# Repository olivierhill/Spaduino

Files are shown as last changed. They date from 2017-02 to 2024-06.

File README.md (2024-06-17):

# Spaduino
Arduino sketch that let you talk to your Calspa controller over I2C

Tested on an ATmega328P running at 3.3V/8MHz. Works on a 2012 Cal Spa with a Balboa controller CS6200DV. Other Balboa based controller with "dumb" Top Side displays might work.

Flash your chip with this sketch. You need to connect wires similar to this:

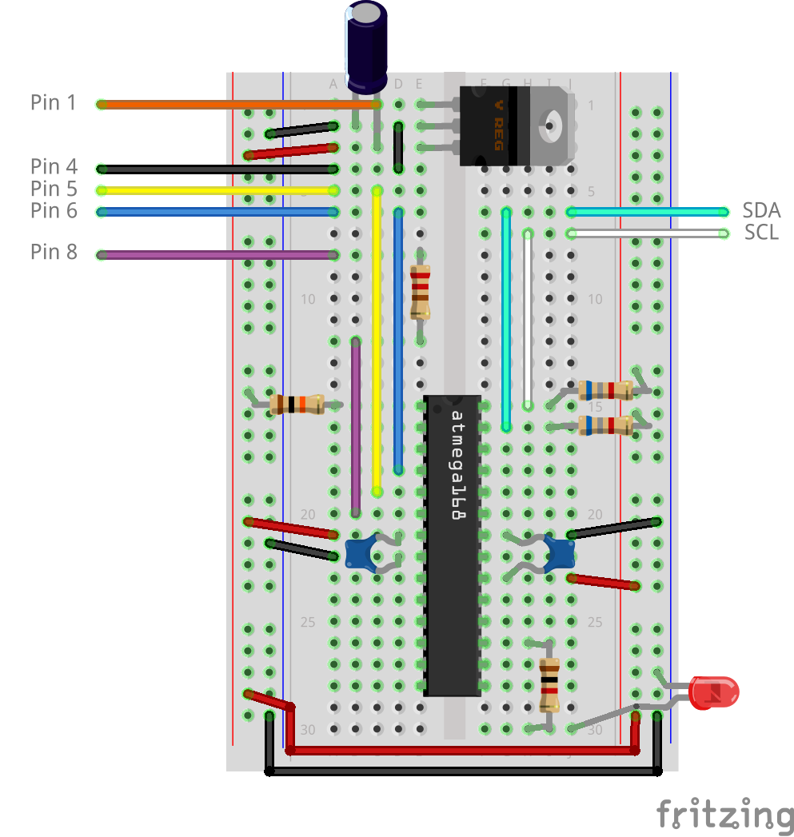
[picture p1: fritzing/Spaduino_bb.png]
Breadboard for Spaduino


I use this setup with a WiFi microcontroller to monitor the hot tub remotely using MQTT.

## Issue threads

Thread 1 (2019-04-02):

Some questions

jantenhove, 2019-04-02:
First of all, thanks for doing the hard work on decoding the protocol.
I want to try to use your project as a starting base for controlling my spa. It has a display with more buttons and a different Balboa controller, but it also has 2 RJ45 connector, so I hope i can reuse (a part) of your code on the second connector.
I have a few questions:
- The balboa spa operates on 5V, the ATmega328P on 3.3V, yet the signals from the spa are directly connected to the Atmega inputs. Are those 3.3V?
- You did not connect the pins 2, 3 and 7. Just because you don't use them? I plan to connect them using the same resistor as the temperature button.

olivierhill, 2019-04-02:
Depending on many buttons the top display has, it might or might not be a different protocol. Some use an SPI protocol instead of the proprietary 7-bit that was coded here.

As for your two questions, the Balboba does operate at 5V. The ATmega is not really 5V tolerant on 3.3V but the clock and data signal are mostly at 0V. If you were to feed a constant 5V it would fry the ATmega. If you really want to be safe you can pass these through a voltage divider or a CMOS voltage converter. A bunch of 78xx chips can be used for those. I've been running mine since 2016 constantly and it still works.

The other pins are for Pump 1&2 and Lights. You can see the pinout here: https://www.olivierhill.ca/archives/74-Cal-Spa-Connector.html

olivierhill, 2019-04-02:
Depending on many buttons the top display has, it might or might not be a different protocol. Some use an SPI protocol instead of the proprietary 7-bit that was coded here.

As for your two questions, the Balboba does operate at 5V. The ATmega is not really 5V tolerant on 3.3V but the clock and data signal are mostly at 0V. If you were to feed a constant 5V it would fry the ATmega. If you really want to be safe you can pass these through a voltage divider or a CMOS voltage converter. A bunch of 78xx chips can be used for those. I've been running mine since 2016 constantly and it still works.

The other pins are for Pump 1&2 and Lights. You can see the pinout here: https://www.olivierhill.ca/archives/74-Cal-Spa-Connector.html

Closed 2019-04-03.

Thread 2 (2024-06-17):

CalSpas 407T and CS6215R1A

smitterer, 2024-06-17:
Hi!

I see this repository wasn't updated for a pretty long time but also the controller is pretty old, so might not be a problem.

Do you know if this would work with CalSpas 407T and CS6215R1A?

BTW, the link to http://www.olivierhill.ca/archives/74-Cal-Spa-Connector.html doesn't work.

Thanks!

olivierhill, 2024-06-17:
I do not own the spa anymore, the controller looks similar to what I had with an 8 pin plug, but I cannot make any guarantee, this is just code I used in the past, YMMV

smitterer, 2024-06-17:
Thanks for your feedback.
Did yours just have the 8 pin plug (Molex) and still use the RJ45 or did you go via the 8 pin plug?

How did you then connect to the atmega? Via an esp?

Thanks!

Closed 2024-06-17.

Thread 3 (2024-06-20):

RJ45 or 8 Pin Molex

smitterer, 2024-06-20:
Hi!

Did you use the RJ45 or a Molex-Connector?

Would you be able to republish https://www.olivierhill.ca/archives/74-Cal-Spa-Connector.html / make it public again?

Thanks!

olivierhill, 2024-06-20:
Please understand this is a bug tracker and not a support forum. You can send PRs and the code is provided as-is according to the attached license.

You can thank AI for the destruction of web pages, I do not have archives.

Closed 2024-06-20.

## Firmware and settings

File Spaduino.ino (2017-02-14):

/*
 * Copyright 2017 Olivier Hill
 * 
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
 * You should have received a copy of the GNU General Public License
 * along with this program.  If not, see <http://www.gnu.org/licenses/>.
**/

#include <Wire.h>
#include <avr/sleep.h>
#include <avr/power.h>

//#define DEBUG 1

const uint8_t PUSH_DELAY = 100; // Seems to want ~100ms for debouncing
const byte    MY_ADDRESS = 82;  // I2C Address

uint32_t buf;
volatile __uint24 display;
volatile boolean changed;

struct 
{
  char    c_str[4];
  uint8_t int_v;
  uint8_t target;
} temperature;

// list of commands
enum {
  CMD_ID      = 1, // ID of device (always answers 0xBA)
  CMD_DISPLAY = 2, // Current display, temperature or message
  CMD_SETTEMP = 3, // Set target temperature
  CMD_GETTEMP = 4, // Get current target temperature
  CMD_STATUS  = 5  // Get current status (heater running, etc.)
};

volatile struct 
{
  byte command;
  byte argument;
  bool in_progress;
} request;
    
void setup()
{
  // disable ADC
  ADCSRA = 0;
  ACSR = bit(ACD); //Disable the analog comparator

  // Running on internal 8MHz clock, but could use this for an Arduino
  //CLKPR = _BV(CLKPCE);
  //CLKPR = 0x01; // 8MHz

  power_adc_disable();    // ADC
  power_spi_disable();    // SPI
  power_usart0_disable(); // Serial
  power_timer1_disable(); // Timer 1

  // I2C Slave
  Wire.begin (MY_ADDRESS);
  Wire.onReceive(receiveEvent);
  Wire.onRequest(requestEvent);

  // Disable internal pullups
  digitalWrite(SDA, 0);
  digitalWrite(SCL, 0);

  pinMode(2,  INPUT);  // CLK
  pinMode(3,  INPUT);  // Data
  pinMode(4,  INPUT);  // Temperature
  pinMode(11, OUTPUT); // Counter toggle
  pinMode(13, INPUT);  // Disable status LED

  // interrupt for SS rising edge (pin 2)
  EICRA &= ~(bit(ISC00) | bit (ISC01));  // clear existing flags
  EICRA |=  bit (ISC01) | bit (ISC00);   // rising edge interrupt
  EIFR   =  bit (INTF0);    // clear flag for interrupt 0
  EIMSK |=  bit (INT0);     // enable it
 
  // reset Timer 2
  TCCR2A = 0;
  TCCR2B = 0;
  
  // Timer 2
  // 8 MHz clock, prescale of 32
  // 125 ns per tick * 32 = 4 µs
  // Count 125 gives 500 µs (0,5 ms)
  TCCR2A = bit (WGM21) | bit (COM2A0);   // CTC mode, toggle on pin 10
  OCR2A  = 124;

  // Timer 2 interrupt
  TIMSK2 = bit (OCIE2A);

  // Reset count to 0
  TCNT2 = 0;

#ifdef DEBUG
  Serial.begin(74880);
  Serial.println(F("Started"));
#endif
}

// CLK rising ISR
ISR (INT0_vect)
{
  // Grab pin before it changes
  byte c = PIND;

  // Test if we are in "writing mode", was Timer 2 started yet?
  if (TCCR2B) {
    TCNT2 = 0; // Reset our counter to zero
  }
  else {
    buf = 0xAA;  // Initial value (padding)

    OCR2A = 124; // Count to 125
    TCNT2 = 0;   // Reset counter to zero

    // Start Timer 2
    TCCR2B = bit (CS21) | bit (CS20); // prescaler of 32
  }

  // Shift buffer and add our pin value
  buf <<= 1;
  buf |= (c >> 3) & 0x01;
} // end of INT0_vect

ISR (TIMER2_COMPA_vect) 
{
  TCCR2B = 0; // stop timer 2 (we keep TCCR2A set for CTC next cycle)
  TCNT2  = 0; // For next timer loop, reset to zero

  // Test if we have a complete 3x7 bit sequence
  if (buf >> 21 == 0xAA)
  { 
    buf &= 0x001fffff; // Only keep 21 bits

    if (display != buf) {
      display = buf;
      changed = true;
    }
  }
}

// called by interrupt service routine when incoming data arrives
void receiveEvent (int howMany)
{
  request.command = Wire.read();

  if (howMany > 1) {
    request.argument = Wire.read();
  }

  request.in_progress = false;

  // Empty buffer to /dev/null
  while (Wire.available () > 0) 
    Wire.read ();

} // end of receiveEvent

void requestEvent()
{
  switch (request.command)
  {
    case CMD_ID:
      Wire.write(0xBA);
      break;
    case CMD_DISPLAY:
      // Temperature is updated in main loop, simply output
      // the buffer here, we are in an ISR
      Wire.write(temperature.c_str, sizeof temperature.c_str );
      break;
    case CMD_GETTEMP:
      Wire.write(temperature.target);
      break;
    case CMD_STATUS:
      byte status = (display >> 14) & 0x0f;
      Wire.write(status);
      break;
  }
}

char getChar(byte c)
{
  // This will generate a lookup table from 7-segment
  // display to ASCII chars. Some chars are represented
  // by a number instead of letter (ie: O is 0).
  switch (c) {
    case 0x7e:
      return '0';
    case 0x30:
      return '1';
    case 0x6d:
      return '2';
    case 0x79:
      return '3';
    case 0x33:
      return '4';
    case 0x5b:
      return '5';
    case 0x5f:
      return '6';
    case 0x70:
      return '7';
    case 0x7f:
      return '8';
    case 0x73:
      return '9';
    case 0x77:
      return 'A';
    case 0x1f:
      return 'b';
    case 0x0d:
      return 'c';
    case 0x4e:
      return 'C';
    case 0x3d:
      return 'd';
    case 0x4f:
      return 'E';
    case 0x47:
      return 'F';
    case 0x37:
      return 'H';
    case 0x0e:
      return 'L';
    case 0x15:
      return 'n';
    case 0x67:
      return 'P';
    case 0x05:
      return 'r';
    case 0x0f:
      return 't';
    case 0x3e:
      return 'U';
    case 0x3b:
      return 'Y';
    case 0x01:
      return '-';
    case 0x00:
      return ' ';
    default:
      return '?';
  }
}

char getLetter(byte c)
{
  switch(c) {
    case '5':
      return 'S';
      break;
    case '1':
      return 'I';
      break;
    case '0':
      return 'O';
      break;
    default:
      return c;
  }
}

void getDisplay()
{
  __uint24 dispCopy = display; // Grab before it changes

  dispCopy &= 0x1c3fff; // Discard what's not on display (3rd byte LSB)

  for (int8_t i=2; i>=0; i--) {
    if (i < 2 && temperature.c_str[2] >> 6 != 0) // Not a digit
      temperature.c_str[i] = getLetter(getChar(dispCopy >> ((2-i)*7) & 0x7f));
    else
      temperature.c_str[i] = getChar(dispCopy >> ((2-i)*7) & 0x7f);
  }
  temperature.c_str[3] = 0x00;

  // Is it a valid numerical temperature? If not, translate to letters
  temperature.int_v = atoi(temperature.c_str);
}

void togglePin(uint8_t pin)
{
#ifdef DEBUG
  Serial.print(millis());
  Serial.print(F(": Toggling pin "));
  Serial.println(pin, HEX);
#endif

  pinMode(pin, OUTPUT);
  digitalWrite(pin, HIGH);
  delay(PUSH_DELAY);
  digitalWrite(pin, LOW);
  pinMode(pin, INPUT); // Hi-Z
}

bool waitForBlink()
{
  // Wait for display to blink
  for (uint8_t j=0; j < 30; j++) { // Wait for 3 sec max. (30 x 100ms)
    if (!changed || display & 0x3fff != 0) {
      delay(100);
    }
    else {
      changed = false; // Reset our change flag to see next temp
      return true;
    }
  }
  return false;
}

// main loop
void loop (void)
{
  // Make sure we run it once between receiveEvent and requestEvent
  if (request.in_progress == false)
  {
    request.in_progress = true;

    switch (request.command) {
      case CMD_DISPLAY:
#ifdef DEBUG
        Serial.print(millis());
        Serial.println(F(": Reading display"));
#endif
        getDisplay();
        break;
      case CMD_SETTEMP:
#ifdef DEBUG
        Serial.println();
        Serial.println(String(millis()) + F(": Trying to set temperature to: ") + String(request.argument, DEC));
#endif

        changed = false;
        togglePin(4);

        waitForBlink();
        
        for (uint8_t i=0; i < 40; i++) { // Up to 40 button push
          // wait for change and a valid temp
          for (uint8_t j=0; j < 20; j++) { // Wait for 2 sec max. (20 x 100ms)
            if (!changed || temperature.int_v < 80) {
              delay(100);
              getDisplay();
            }
            else
              break;
          }

          if (temperature.int_v < 80) {
#ifdef DEBUG
            Serial.println(String(millis()) + F(": Something went wrong"));
#endif
            break;
          }

#ifdef DEBUG
          Serial.print(millis());
          Serial.print(F(": Current target is: "));
          Serial.println(temperature.int_v, DEC);
#endif

          if (temperature.int_v == request.argument) {
#ifdef DEBUG
            Serial.print(millis());
            Serial.println(F(": All done"));
#endif
            temperature.target = temperature.int_v;
            break;
          }
          else {
            changed = false;
            togglePin(4);
            //delay(200);
          }
        }
        break;
      case CMD_GETTEMP:

#ifdef DEBUG
        Serial.print(millis());
        Serial.println(F(": Reading current target temp"));
#endif
        changed = false;
        togglePin(4);

        waitForBlink();

        // wait for change and a valid temp
        for (uint8_t j=0; j < 20; j++) { // Wait for 2 sec max.
          if (!changed || temperature.int_v < 80) {
            delay(100);
            getDisplay();
          }
          else
            break;
        }

#ifdef DEBUG
        if (temperature.int_v < 80) {
          Serial.print(millis());
          Serial.println(F(": Something went wrong"));
        }
#endif
      
        changed = false;
        temperature.target = temperature.int_v;
        break;
        
    } // end switch
  } // end if in progress
} // end of loop

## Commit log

2017-02-07 Adding fritzing
    [Spaduino.fzz]
2017-02-07 Better letter detection, reduces code size and fixes a race condition
    [Spaduino.ino]
2017-02-08 Put correct AVR chip
    [Spaduino.fzz]

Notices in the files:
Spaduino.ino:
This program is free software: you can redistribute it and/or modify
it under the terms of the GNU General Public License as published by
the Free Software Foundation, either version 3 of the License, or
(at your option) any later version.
